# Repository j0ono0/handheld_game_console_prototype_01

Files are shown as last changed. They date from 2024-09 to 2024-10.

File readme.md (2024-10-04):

# Handheld game console and Arduino game

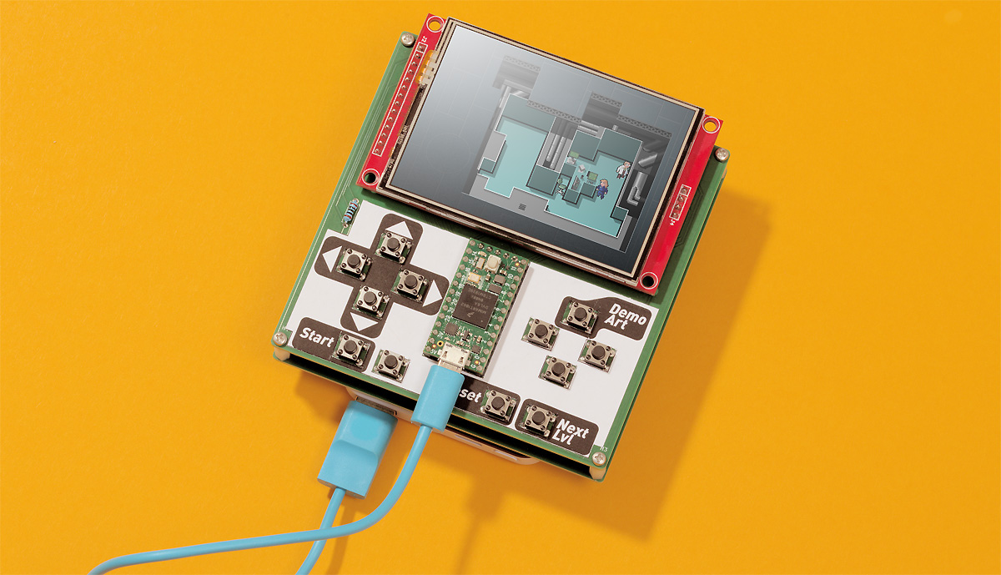
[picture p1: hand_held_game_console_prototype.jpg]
prototype hand-held game hardware


The motivation and goal of this project was primarily as an excuse to try and design my first PCB. Choosing a handheld game console made an appealing form on several points:

- Has enough wiring to be an interesting, but achievable with no prior experience
- Makes a useful progression from a breadboard prototype
- Results in an artifact that has broad appeal and is fun showing off to tech, and non-tech, friends alike  

To fully realise success I needed a game to run on the hardware. To Achieve this requirement I chose to appropriate the key game mechanic of Sokoban (designed in 1981 by Hiroyuki Imabayashi, and first published in December 1982 [[wikipedia](https://en.wikipedia.org/wiki/Sokoban)]).

## Hardware

Having a [Teensy 4](https://www.pjrc.com/store/teensy40.html) and [TFT screen](https://www.pjrc.com/store/display_ili9341_touch.html) on hand set some initial design constraints. The microcontroller has generous limitations and made for fast firmware development without the need for much attention to optimisation.

The initial wiring was tested on a bread-board with microcontroller and screen communicating via SPI. Several input buttons were multiplexed, not due to lack of gpio pins, but simply to try out a technique new to me. At this point the hardware worked reliably but was somewhat unwieldy to press buttons and move around my desk whilst developing the game. 

The screen module includes touch input and an SD card reader. In the spirit of making a fully-featured development device I decided to enable these additional components. Once connected on the bread-board the hardware ceased to work reliably. Testing individually each did work correctly making for a hopeful outlook. I decided to forge ahead and include these components after ponder failure/fix scenarios:

- Bread-board/wiring issue - Issue will be fixed with PCB wiring
- Faulty hardware - I can cut traces on the PCB effectively 'removing' components
- Firmware error - Not initialising components or changing code/libraries should resolve errors

With a somewhat working bread-board prototype I moved onto designing a PCB with [KiCad](https://www.kicad.org/). Component placement was dictated largely by functional requirements of being a hand-held game console. Routing wires became a puzzle that included reconfiguring pin functions of the microcontroller for most efficient outcomes. Amongst advice I gained during this process was to print out and place parts before finalising the design which proved to be golden as I picked up a measurement error in a footprint I created. I also created some simple graphics for the silkscreen to test that process.

Prior to commencing the PCB design I selected [PCBWay](https://www.pcbway.com/) for fabrication. My choice was primarily driven by price and website usability/clarity. Opting for the cheapest configuration (I had no real confidence this project would work out) guided maximum PCB size and some other KiCad settings to meet fabrication requirements. On completion of the design, submission of files was straight forward with good documentation on the PCBWay website to guide the process. Fabrication and delivery was _fast_, 5 day turn-a-round with the vast majority of that time being transit to/through Australia. The novelty of holding my own, high quality and professionally manufactured, PCB is still exciting a few weeks later as I write-up this project summary. The PCB looks excellent including the silkscreen test graphics which is encouraging to try out some more demanding artwork for the next project.

Assembly on the PCB was uncomplicated with only through hole components and all parts fitting as intended. Once assembled SPI reliability issues vanished with all components working perfectly. I assume controlling x3 SPI devices was pushing the capabilities of my bread-board. Power and portability was resolved by taping a small battery bank to the reverse side and providing power via the USB plug. This made for a fun prototype to show off on-the-go and easy to swap for tethered development at my desk.

## Firmware

Goals for this section of the project were less defined than the hardware - Something fun to show off and achievable to create. I have a 'secret' ongoing project of creating a roguelike and would very much like it to run on a handheld console. With several attempts of this game genre for desktop under my belt - all of them failures of varying degrees - I decided to set some further constraints around what a 'minimum viable product' might look like. The result is my homage to Sokoban (see intro for details). The code is total overkill for the task at hand but with the thought it might be the groundwork for a more complex roguelike game.

The project utilises the Arduino environment which streamlines access to libraries, interfacing with hardware, and compiling/uploading. Whilst Arduino is essentially C++, I've attempted to primarily write in C compatible code as practice for developing for more restricted hardware devices. 

In the course of processing graphics for embedding into the game I wrote a hand-full of Python scripts. These are a work-in-progress as I experiment and streamline how I create graphical assets (sprites, level maps, and background tiles) and process them for embedding into the code.

At the time of writing this the game is fully functional with 3 levels. The user interface includes buttons to reset, skip levels, plus display a demo art screen. The latter as a talking point for where the graphics may go when showing off the project.

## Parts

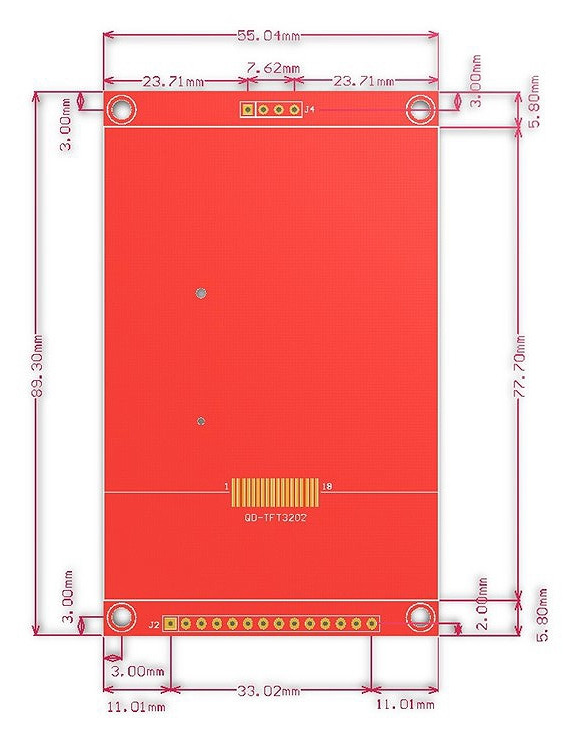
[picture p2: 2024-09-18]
hardware/component specs/display_ili9341_touch32_drawing.png

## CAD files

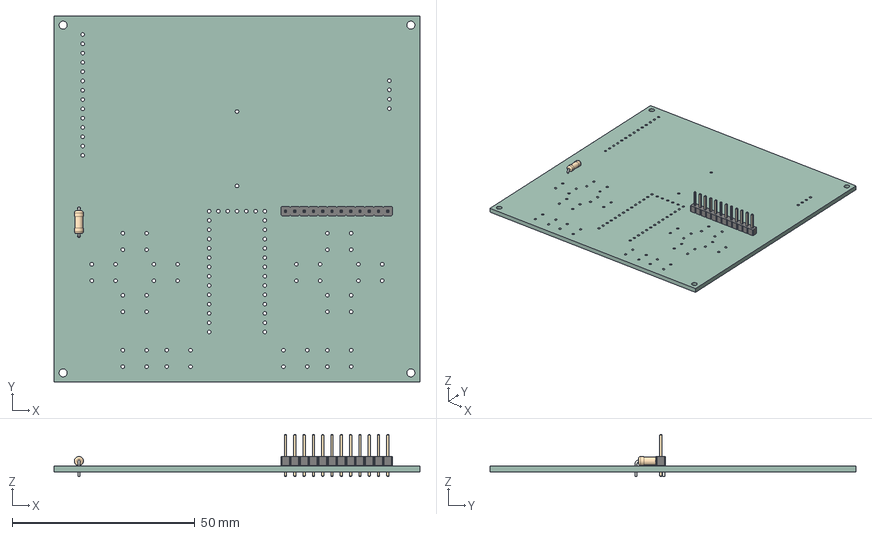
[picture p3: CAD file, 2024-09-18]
hardware/handheld game console/handheld game console.step
100.0 x 100.0 x 11.5 mm
R_Axial_DIN0207_L63mm_D25mm_P762mm_Horizontal
PinHeader_1x12_P254mm_Vertical
handheld game console_PCB

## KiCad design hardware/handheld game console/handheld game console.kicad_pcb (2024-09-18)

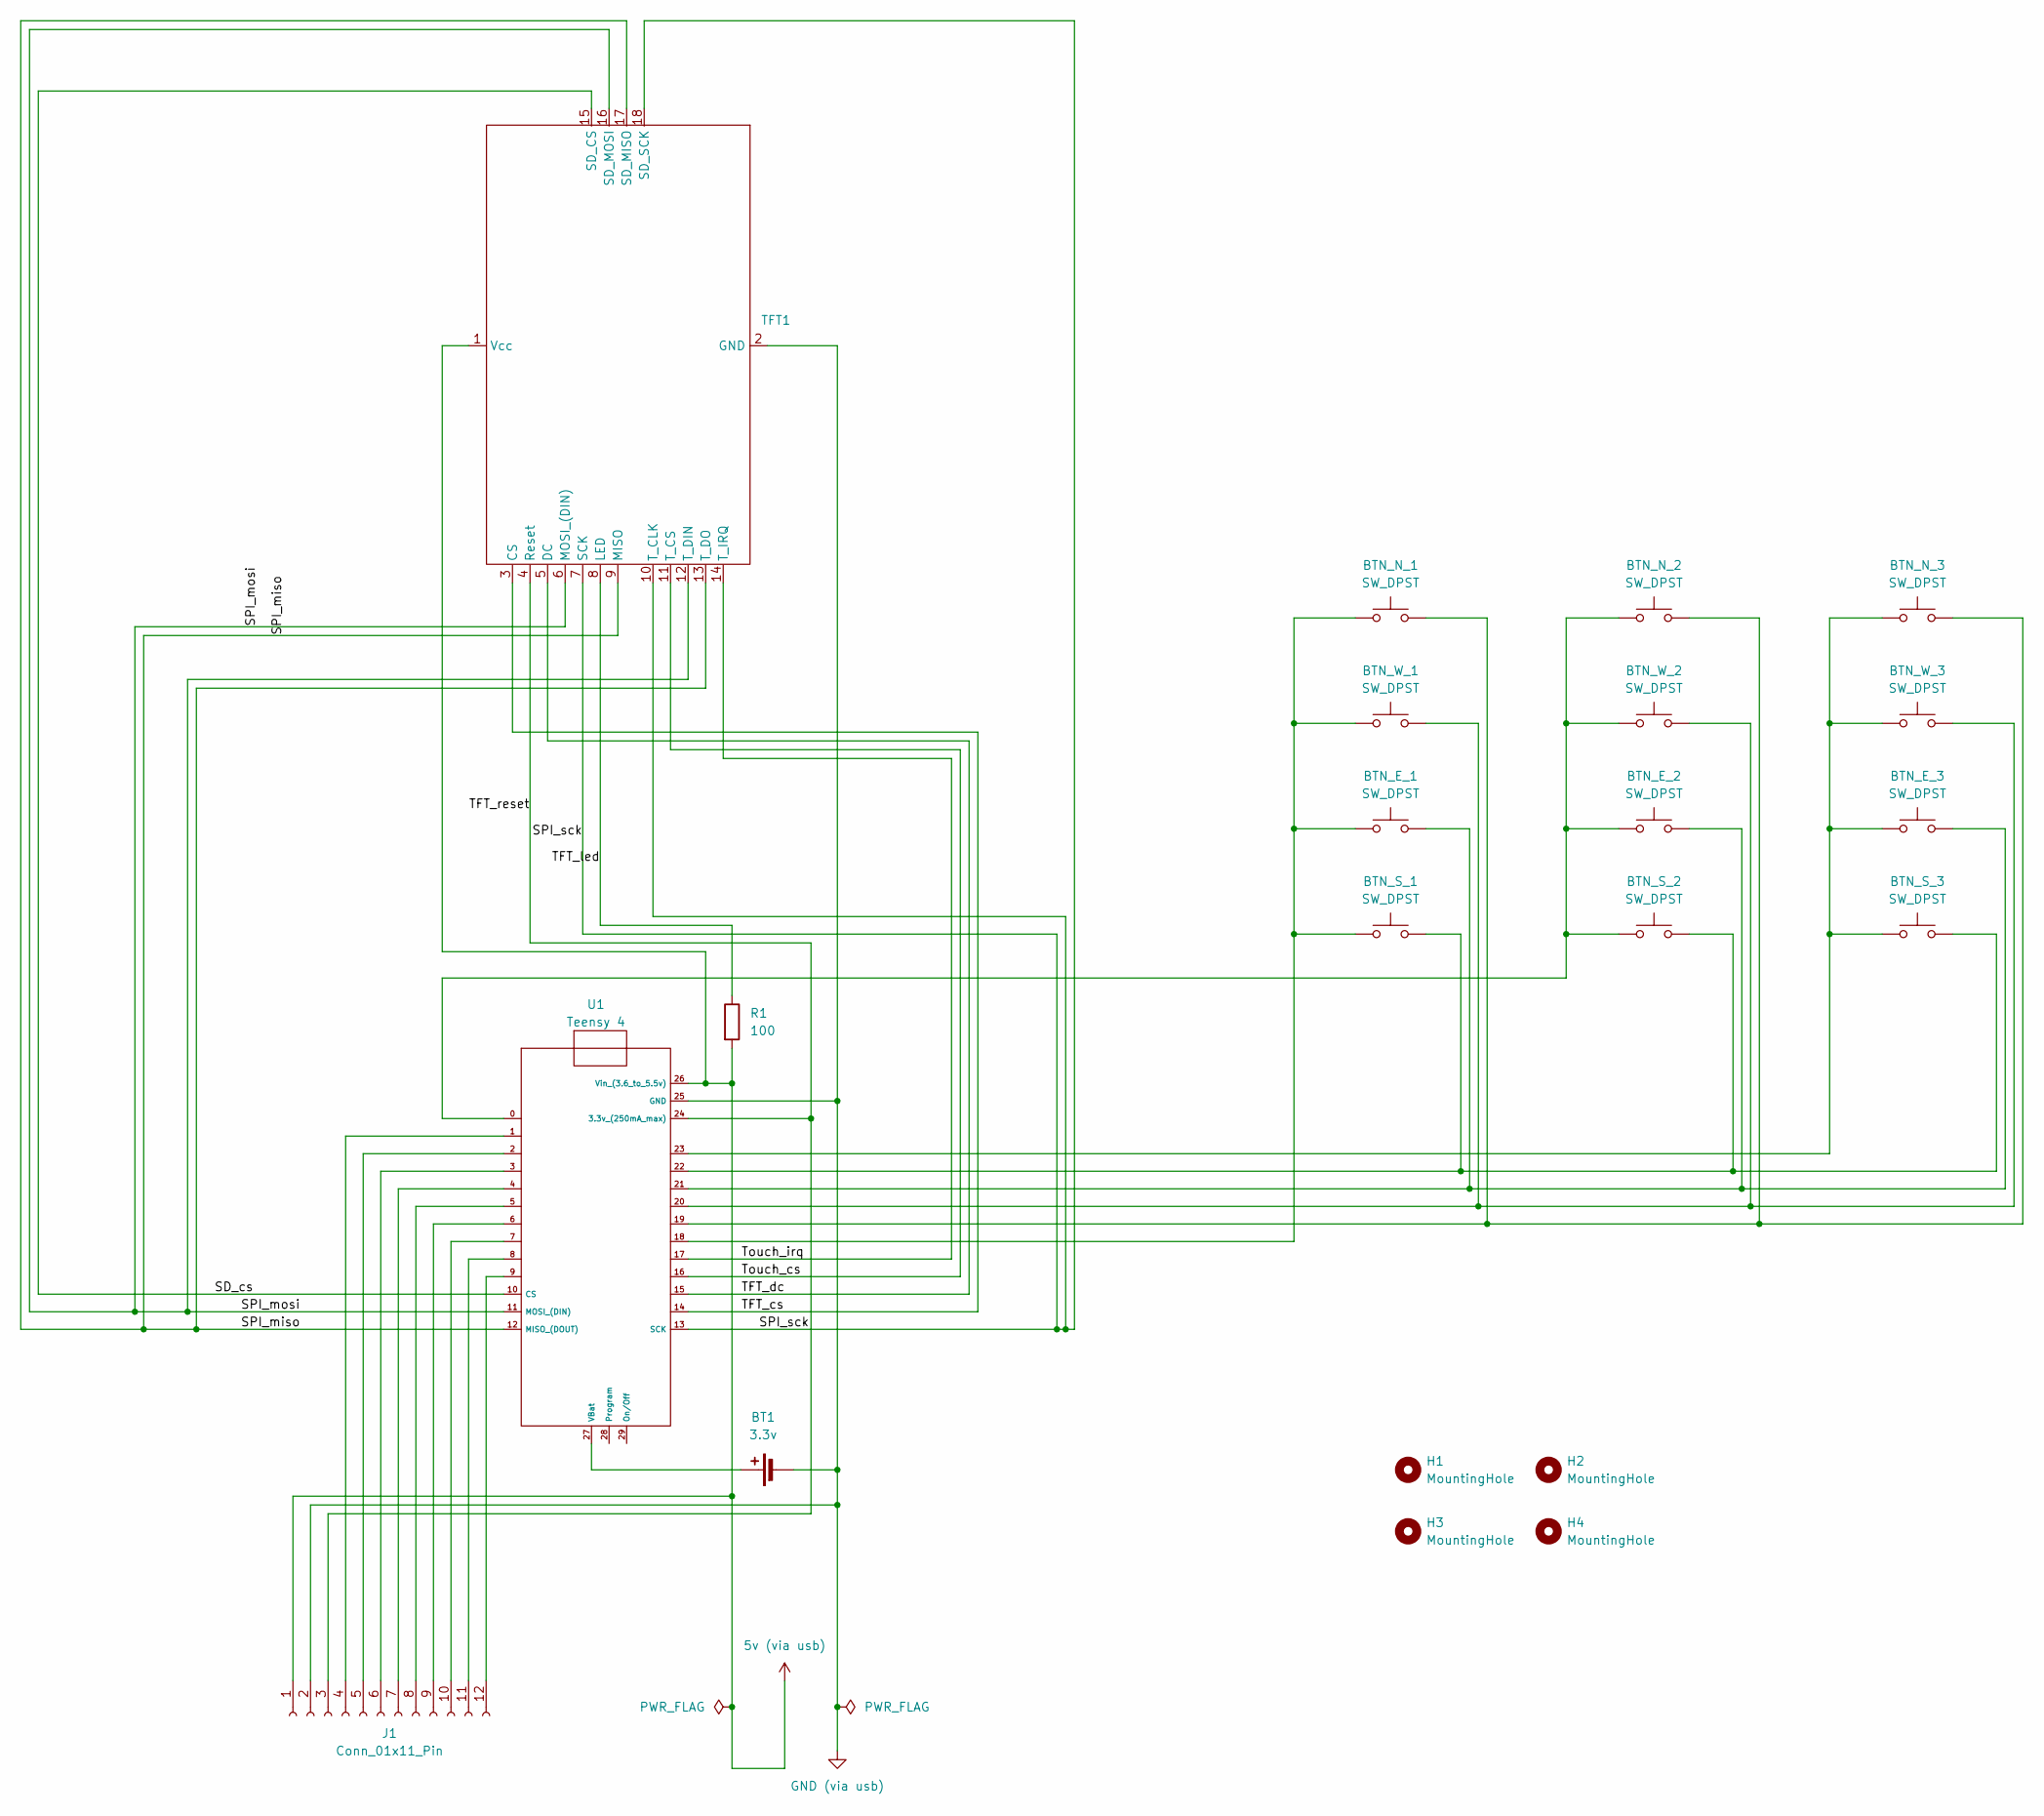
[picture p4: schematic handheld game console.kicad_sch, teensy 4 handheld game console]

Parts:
BT1: 3.3v; Battery_Holder
BTN_E_1, BTN_E_2, BTN_E_3: SW_DPST; tactile switch 6.5 x 4.5
BTN_N_1, BTN_N_2, BTN_N_3: SW_DPST; tactile switch 6.5 x 4.5
BTN_S_1, BTN_S_2, BTN_S_3: SW_DPST; tactile switch 6.5 x 4.5
BTN_W_1, BTN_W_2, BTN_W_3: SW_DPST; tactile switch 6.5 x 4.5
H1, H2, H3, H4: MountingHole; MountingHole_2.2mm_M2
J1: Conn_01x11_Pin; PinHeader_1x12_P2.54mm_Vertical
R1: 100; R_Axial_DIN0207_L6.3mm_D2.5mm_P7.62mm_Horizontal
TFT1: TFT_touchscreen_ili9341_controller_chip
U1: Teensy 4; teensy_4

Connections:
5v (via usb): J1.1, R1.2, TFT1.1 (Vcc), U1.26 (Vin_(3.6_to_5.5v))
/SD_cs: TFT1.15 (SD_CS), U1.10 (CS)
/SPI_miso: TFT1.9 (MISO), TFT1.13 (T_DO), TFT1.17 (SD_MISO), U1.12 (MISO_(DOUT))
/SPI_mosi: TFT1.6 (MOSI_(DIN)), TFT1.12 (T_DIN), TFT1.16 (SD_MOSI), U1.11 (MOSI_(DIN))
/SPI_sck: TFT1.7 (SCK), TFT1.10 (T_CLK), TFT1.18 (SD_SCK), U1.13 (SCK)
/TFT_cs: TFT1.3 (CS), U1.14
/TFT_dc: TFT1.5 (DC), U1.15
/TFT_led: R1.1, TFT1.8 (LED)
/TFT_reset: J1.3, TFT1.4 (Reset), U1.24 (3.3v_(250mA_max))
/Touch_cs: TFT1.11 (T_CS), U1.16
/Touch_irq: TFT1.14 (T_IRQ), U1.17
GND (via usb): BT1.2 (-), J1.2, TFT1.2 (GND), U1.25 (GND)
unnamed: BT1.1 (+), U1.27 (VBat)
unnamed: BTN_E_1.1, BTN_N_1.1, BTN_S_1.1, BTN_W_1.1, U1.18
unnamed: BTN_E_1.2, BTN_E_2.2, BTN_E_3.2, U1.21
unnamed: BTN_E_2.1, BTN_N_2.1, BTN_S_2.1, BTN_W_2.1, U1.0
unnamed: BTN_E_3.1, BTN_N_3.1, BTN_S_3.1, BTN_W_3.1, U1.23
unnamed: BTN_N_1.2, BTN_N_2.2, BTN_N_3.2, U1.19
unnamed: BTN_S_1.2, BTN_S_2.2, BTN_S_3.2, U1.22
unnamed: BTN_W_1.2, BTN_W_2.2, BTN_W_3.2, U1.20
unnamed: J1.4, U1.1
unnamed: J1.5, U1.2
unnamed: J1.6, U1.3
unnamed: J1.7, U1.4
unnamed: J1.8, U1.5
unnamed: J1.9, U1.6
unnamed: J1.10, U1.7
unnamed: J1.11, U1.8
unnamed: J1.12, U1.9

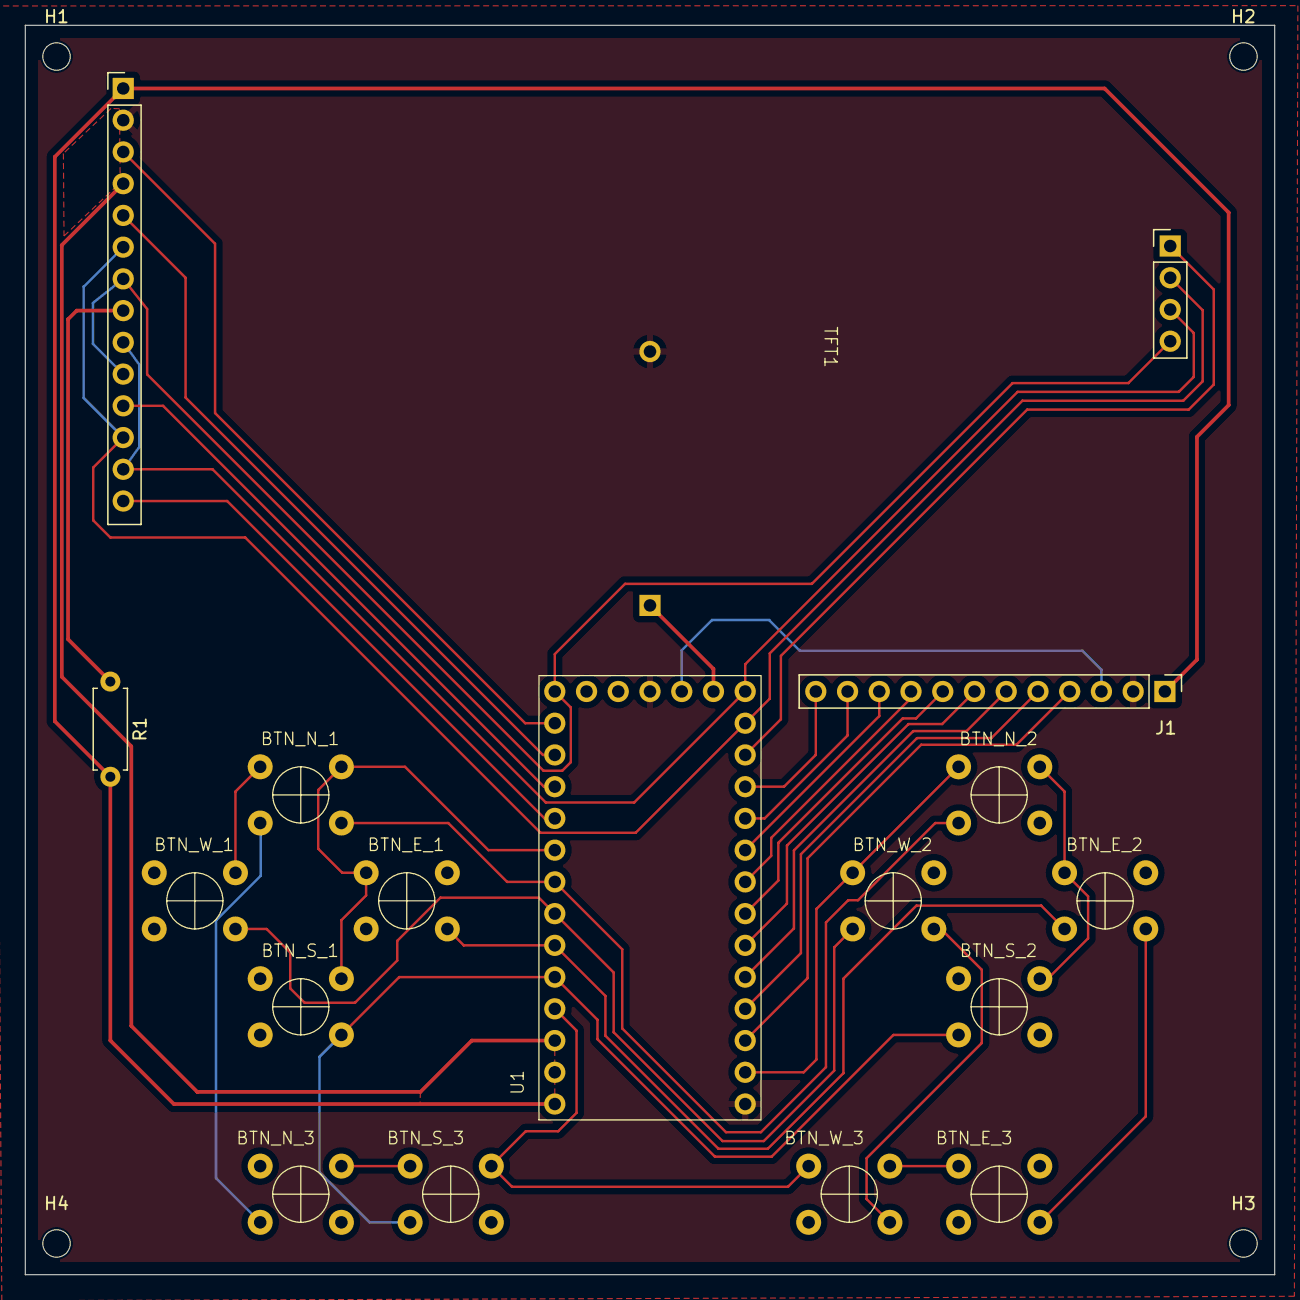
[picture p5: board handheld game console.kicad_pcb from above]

Board: 2 copper layers, 100.0 x 100.0 mm, 21 parts (1 on the bottom side), 29 nets.

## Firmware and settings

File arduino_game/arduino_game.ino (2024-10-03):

/** NOTES **********************

display is 320 x 240

*******************************/

#include "input.h"
#include "engine.h"

// Resources supplied to the game engine to create the game
#include "resources.h"







enum GameMode
{
    gm_intro,
    gm_inGame,
    gm_success,
    gm_end,
};

uint8_t current_env;
GameMode game_mode;

void populate_env(uint8_t env_id)
{
    current_env = env_id;
    populateEntities(environmentList[current_env].entities, environmentList[current_env].entity_count);
    setTerrain(environmentList[current_env].terrain);
    setPalette(environmentList[current_env].palette);
}

void setup()
{

    Serial.begin(9600);

    setupButtonInputs();

    screenSetup();
    game_mode = gm_intro;
    current_env = 0;
    populate_env(current_env);

    while ((millis() <= 1000));
}

void loop()
{
    testTouchscreen();

    // Queue user keypress
    enqueue_kpq(readUserInput());

    ///////////////////////////////////////////////////////////////////
    ///////////////////////////////////////////////////////////////////
    // Dev testing button inputs

    if(kpq_next() == btn_3_w)
    {
        // reset game
        game_mode = gm_intro;
        current_env = 0;
        populate_env(current_env);
        screenIntro();
    }
    else if (kpq_next() == btn_3_e)
    {
        // force game progression
        if (current_env < 2)
        {
            game_mode = gm_success;
            ++current_env;
            populate_env(current_env);
            screenEnvComplete();
        }
        else
        {
            game_mode = gm_end;
            current_env = 0;
            screenSuccess();
        }
    }
    else if (kpq_next() == btn_2_n)
    {
        // show demo screen and wait for any button press
        dequeue_kpq();
        screenDemo1();
        while(dequeue_kpq() == -1){
            enqueue_kpq(readUserInput());
        };
    }
    ///////////////////////////////////////////////////////////////////
    ///////////////////////////////////////////////////////////////////

    // Wait to start game  //////////////////////////////////////////////

    if (game_mode != gm_inGame)
    {
        if (dequeue_kpq() != btn_3_n)
        {
            // Wait for start/cont' keypress
            return;
        }
        switch(game_mode) 
        {
            case gm_intro:
                // Commence new game play
                Serial.println("starting game mode.");
                game_mode = gm_inGame;
                drawAll();
                break;

            case gm_success:
                game_mode = gm_inGame;
                drawAll();
                break;


            case gm_end:
                // cycle game back to splashscreen
                game_mode = gm_intro;
                populate_env(current_env);
                screenIntro();
                

                break;

            default:
                break;
        }
        return;
    }

  

    // Test for end game  //////////////////////////////////////////////

    if (gameSolved())
    {
        // Draw final stationary sprites
        advanceSpriteAnimations();

        Serial.println("game solved!");
        delay(200);

        // Prepare entityStore for next level (or restart)
        if (current_env < 2)
        {
            game_mode = gm_success;
            ++current_env;
            populate_env(current_env);
            screenEnvComplete();
        }
        else
        {
            game_mode = gm_end;
            current_env = 0;
            screenSuccess();
        }

        // Return to loop start
        return;
    }

    // Complete existing movement transitions before running behaviours again ////
    if (!spritesInTransit())
    {
        runBehaviours();
        sortEntityDrawOrder();
    }

    advanceSpriteAnimations();

}

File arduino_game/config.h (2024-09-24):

#ifndef game_config_h
#define game_config_h

// SPI hardware pins
#define TFT_CS 14
#define SD_CS 10
#define XPT_CS 16 // touch cs

#define TFT_DC 15


// #define XPT_IRQ  17


#define PIN_MP_PWR_1 18
#define PIN_MP_PWR_2 0
#define PIN_MP_PWR_3 23

#define PIN_MP_N 19
#define PIN_MP_W 20
#define PIN_MP_E 21
#define PIN_MP_S 22


/*
    Note:
    Terrain grid size is chosen for more effecient graphics.
    Env grid at x2 terrain size makes for better UI.

    ?? Generally everything should be expressed in
    env-grid leaving terrain-grid for lower level functions. ??
*/

#define SCREEN_WIDTH 320
#define SCREEN_HEIGHT 240

// Terrain tiles are split into a grid.
// Each cell of this 'terrain grid' is 8x8 pixels
#define TERRAIN_WIDTH 40
#define TERRAIN_HEIGHT 30
#define TERRAIN_UNIT 8

// Entities are tracked within the an 'environment grid'.
// These grid cells are 16x16 pixels.
#define ENV_WIDTH 20
#define ENV_HEIGHT 15
#define ENV_UNIT 16

#define COLOR_FLOOR 0xbe5c
#define COLOR_FLOOR_TARGET 0x9d9b
#define COLOR_BOX 0xc4c7
#define COLOR_BOX_ACTIVE 0xfb42
#define COLOR_WALL 0x8494
#define COLOR_PLAYER 0x3c04
#define COLOR_WATER 0x25b9

#define COLOR_TRANSPARENT 0x07e0

#define MAX_ENTITIES 100

#endif

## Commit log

2024-06-29 working linked list version (might have memory bug!)
    [arduino_game.ino, engine.cpp]
2024-07-01 track terrain and asset location by array
2024-07-25 update main loop and bug fixes
    [arduino_game.ino, engine.cpp]
2024-08-15 update gameSolution to include powerconverters
2024-08-26 move resources access via arduino_game.ino
2024-08-28 animated sprite attempt (fail)
    [config.h, engine.cpp]
2024-08-30 add variable frame rates for sprites.
2024-09-18 add hardware
    [handheld game console-B_Cu.gbr, handheld game console-B_Mask.gbr, handheld game console-B_Paste.gbr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]
